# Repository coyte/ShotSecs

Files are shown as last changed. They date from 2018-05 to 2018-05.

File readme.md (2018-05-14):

# ShotSecs
Created a little timer that will keep track of how long power (240v) is applied. Originally developed to measure Espresso shots time, but probably useful for other applications.
The usual warnings about tinkering with 240V AC apply!!!

### Introduction
The original idea was that the logic and PSA would be housed inside the espressomachine, and the 7 segment display would be glued/mounted to the exterior of the machine. Hence they are two separate parts connected by a 10-strand data cable
### Hardware
The hardware consists of a little PCB (Kicad schematic & layout included) that hold a Atmega328p, two transistors and 10 resistors to control the 7-segment display.
On the input side I used some resistors and a optocoupler to detect power applied.
PSU, Atmega, optocoupler, resistors and transistors is mounted on the same PCB (220V and 5 V), intended to be drowned in a resin box when donw.

#### Connections (240Volts)
The timer needs a regular 240V connection to power up the Atmega and display. In addition it needs a connection of the applied power
Connect either P-N-Pd or N-P-Nd on the tree terminal block.
Where   P = phase or live wire from 240V mains
        N = null or neutral wire from 240V mains
        Pd= Phase from device to be measured
        Nd= null from device to be measured

### Software
The software is written in AVR C. It essentially is a timer that runs while power is detected by the optocoupler. The display will 'hold' the last known value if power is stopped. On re-applying the power the timer will restart at 0.

Have fun and be careful.

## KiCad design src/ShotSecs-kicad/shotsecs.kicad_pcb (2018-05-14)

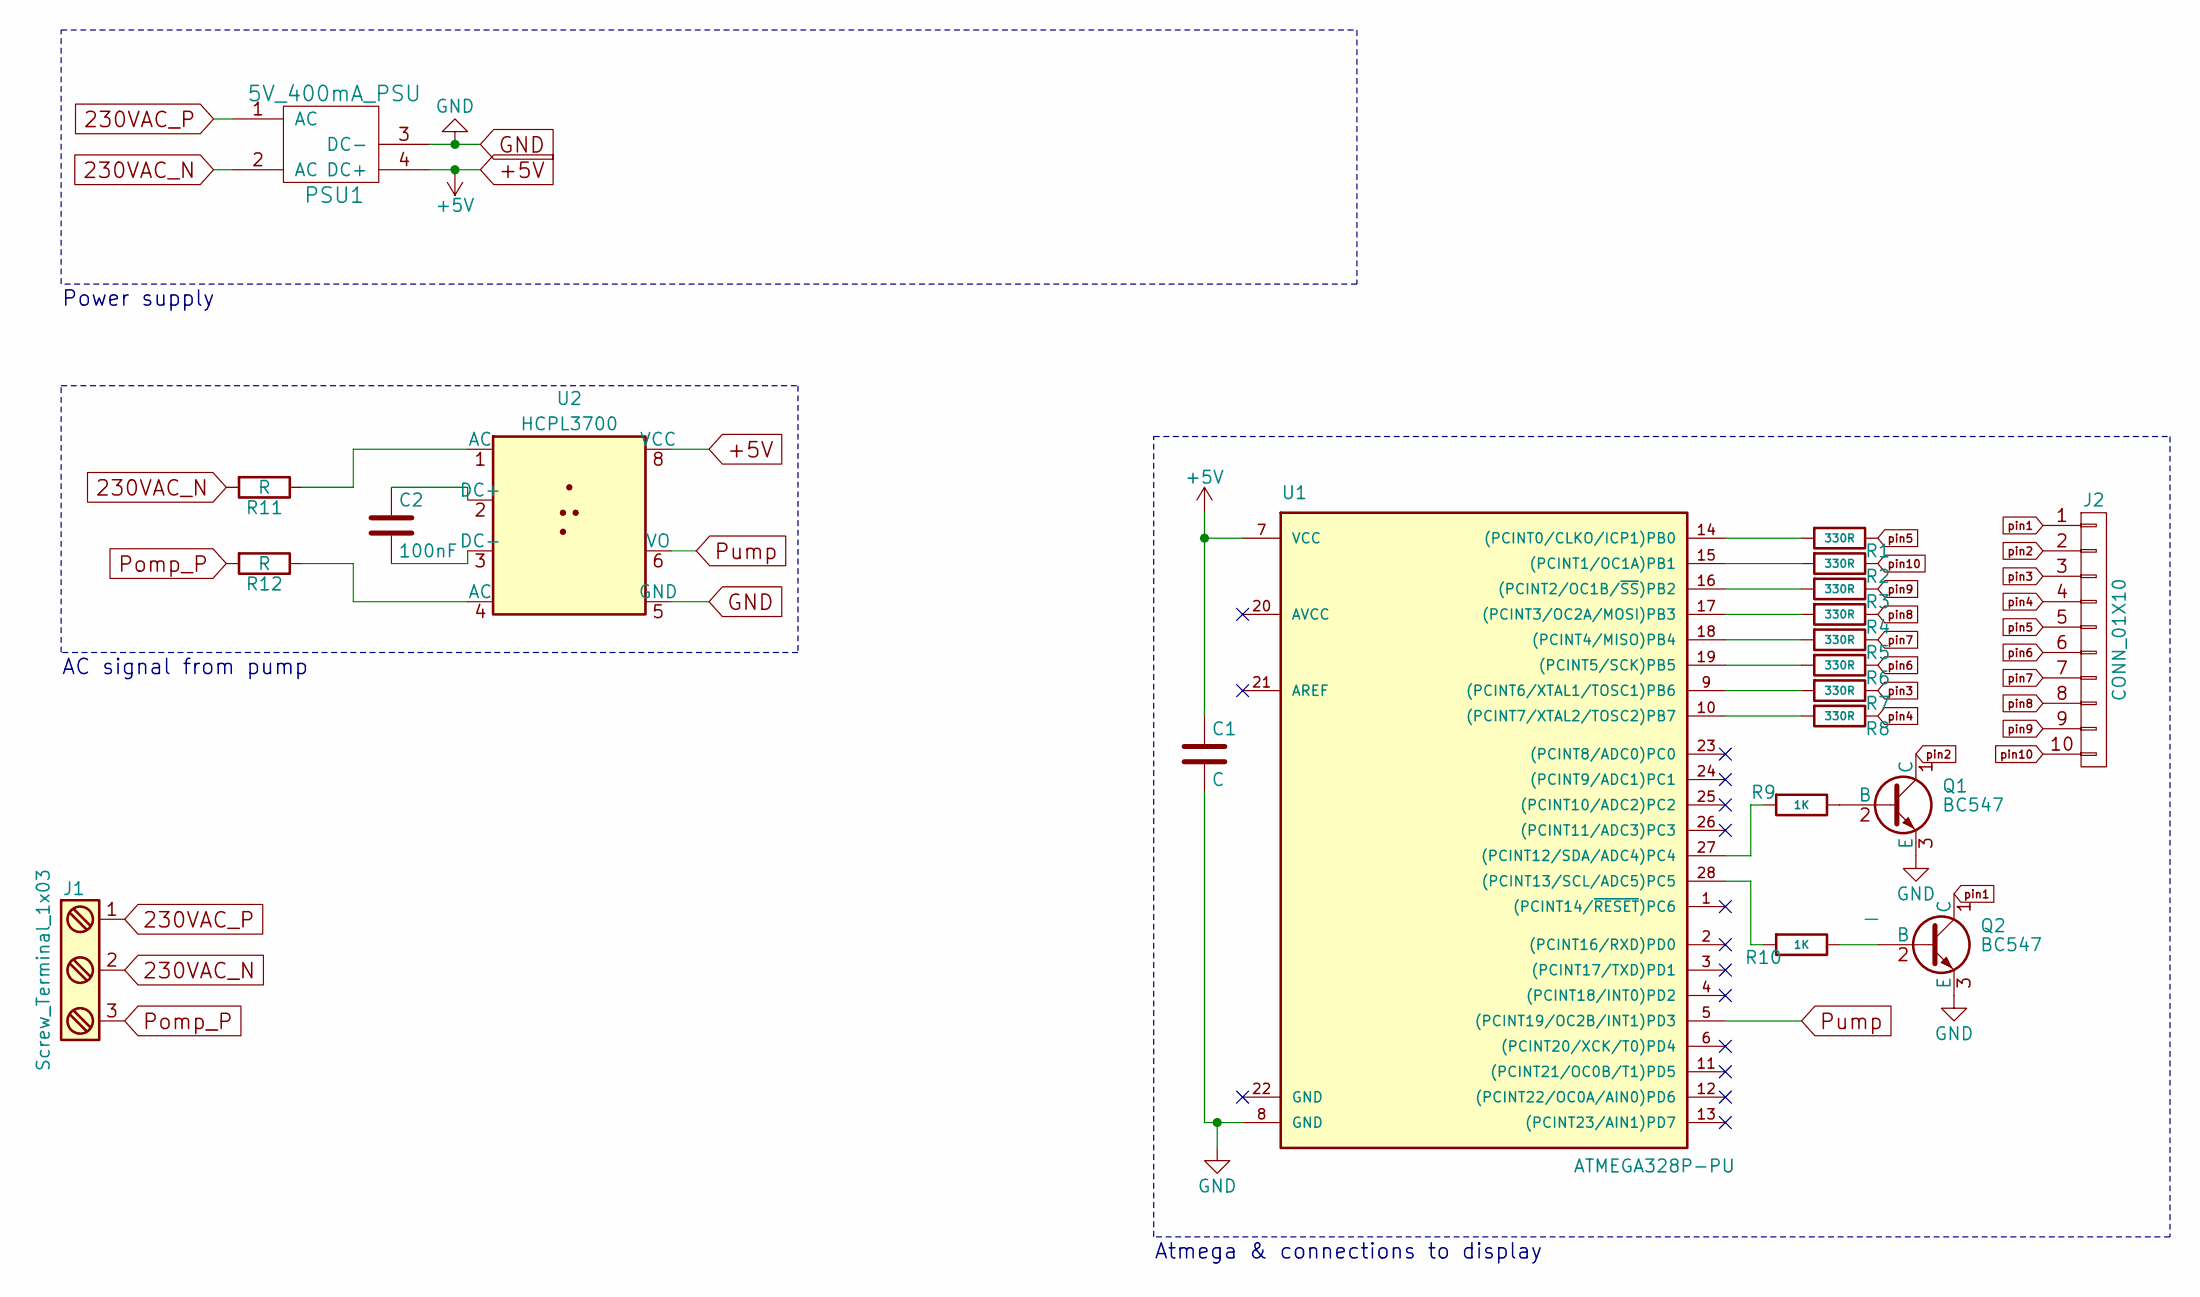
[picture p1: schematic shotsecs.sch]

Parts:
C1: C; C_Disc_D3.8mm_W2.6mm_P2.50mm
C2: 100nF; CP_Radial_D8.0mm_P5.00mm
J1: Screw_Terminal_1x03; TerminalBlock_Pheonix_PT-3.5mm_3pol
J2: CONN_01X10; Pin_Header_Straight_1x10_Pitch2.54mm
PSU1: 5V_400mA_PSU; HLK-PM01
Q1, Q2: BC547; TO-92_Molded_Narrow
R1, R2, R3, R4, R5, R6, R7, R8: 330R; R_Axial_DIN0207_L6.3mm_D2.5mm_P7.62mm_Horizontal
R9, R10: 1K; R_Axial_DIN0207_L6.3mm_D2.5mm_P7.62mm_Horizontal
R11, R12: R; R_Axial_DIN0207_L6.3mm_D2.5mm_P7.62mm_Horizontal
U1: ATMEGA328P-PU; DIP-28_W7.62mm
U2: HCPL3700; DIP-8_W7.62mm

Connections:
230VAC_N: J1.2, PSU1.2 (AC), R11.2
230VAC_P: J1.1, PSU1.1 (AC)
+5V: C1.1, PSU1.4 (DC+), U1.7 (VCC), U2.8 (VCC)
GND: C1.2, PSU1.3 (DC-), Q1.3 (E), Q2.3 (E), U1.8 (GND), U2.5 (GND)
unnamed: C2.1, U2.2 (DC+)
unnamed: C2.2, U2.3 (DC-)
unnamed: Q1.2 (B), R9.1
unnamed: Q2.2 (B), R10.1
unnamed: R1.2, U1.14 ((PCINT0/CLKO/ICP1)PB0)
unnamed: R2.2, U1.15 ((PCINT1/OC1A)PB1)
unnamed: R3.2, U1.16 ((PCINT2/OC1B/~SS~)PB2)
unnamed: R4.2, U1.17 ((PCINT3/OC2A/MOSI)PB3)
unnamed: R5.2, U1.18 ((PCINT4/MISO)PB4)
unnamed: R6.2, U1.19 ((PCINT5/SCK)PB5)
unnamed: R7.2, U1.9 ((PCINT6/XTAL1/TOSC1)PB6)
unnamed: R8.2, U1.10 ((PCINT7/XTAL2/TOSC2)PB7)
unnamed: R9.2, U1.27 ((PCINT12/SDA/ADC4)PC4)
unnamed: R10.2, U1.28 ((PCINT13/SCL/ADC5)PC5)
unnamed: R11.1, U2.1 (AC)
unnamed: R12.1, U2.4 (AC)
Pomp_P: J1.3, R12.2
Pump: U1.5 ((PCINT19/OC2B/INT1)PD3), U2.6 (VO)
pin1: J2.1, Q2.1 (C)
pin2: J2.2, Q1.1 (C)
pin3: J2.3, R7.1
pin4: J2.4, R8.1
pin5: J2.5, R1.1
pin6: J2.6, R6.1
pin7: J2.7, R5.1
pin8: J2.8, R4.1
pin9: J2.9, R3.1
pin10: J2.10, R2.1

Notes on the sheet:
Power supply
AC signal from pump
Atmega & connections to display

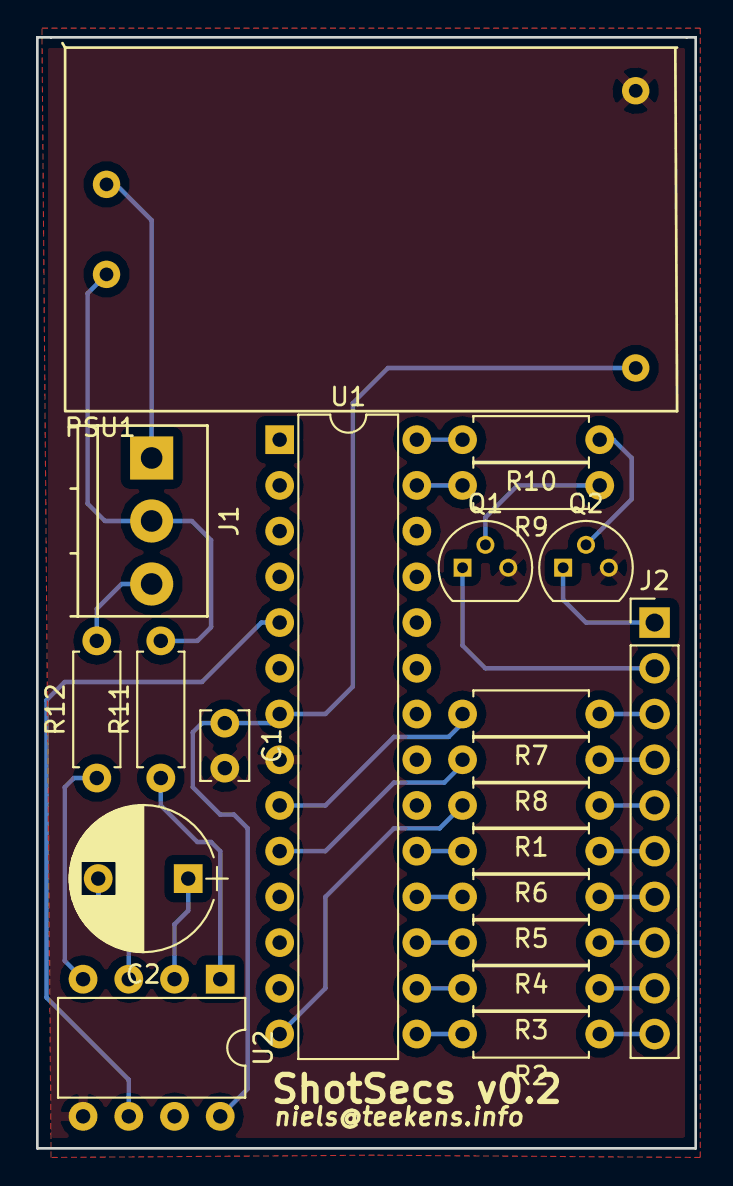
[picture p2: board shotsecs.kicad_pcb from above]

Board: 2 copper layers, 36.6 x 61.7 mm, 21 parts (0 on the bottom side), 32 nets.

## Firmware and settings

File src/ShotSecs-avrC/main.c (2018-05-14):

//Counter for espresso machine shot time.
//Fuses (L H E): E3 DA FD

#define F_CPU	4000000UL
#include <avr/io.h>
#include <util/delay.h>
#include "usart.h"


#define SegOne   0x20 //Activates digit 1
#define SegTwo   0x10 //activates digit 2

void main() {
    int debug=0; //set to 0 to disable debug msgs
	if (debug) USART_init(); // Initialize USART
	char seg_code[]={0x3f,0x6,0x5b,0x4f,0x66,0x6d,0x7c,0x7,0x7f,0x67}; //array of hex representations of decimal digits
    char seg_codeDP[]={0xbf,0x86,0xdb,0xcf,0xe6,0xed,0xfc,0x87,0xff,0xe7}; //array of hex representations of decimal digits, plus decimal point active
    int cnt,i;
	char String[4];
	cnt=0;
    
    
    /* Configure the ports as output */
    DDRB = 0xff; // Data lines
    DDRC = 0xff; // Control signal PORTC4-PORTC5
    DDRD = 0x00; // Input for motor
    PORTD = (1 << 3); //Enable pull-up


	void display(int counter) //Display the counter on the 7-segment display 
	{
		int time = 0;
		int seg1,seg2 = 0;
		if (counter<100) time = 10; else time=102; //time to keep tenths and wholes in display
		
		for (i = 0; i < time; i++) //loop to keep same digit displayed for a while
		{
			PORTC = SegOne; //segment one
			if (counter<100) 
			{
				seg1 = counter / 10;
				PORTB = seg_codeDP[seg1];
			}
			else
			{
				seg1 = (counter-100) / 10;
				PORTB = seg_code[seg1]; 
			}	
			_delay_ms(10);

			PORTC = SegTwo; //segment two
			if (counter<100) 
			{
				seg2 = counter % 10;
				PORTB = seg_code[seg2];
			}
			else
			{
				seg2 = (counter-100) % 10;
				PORTB = seg_code[seg2]; 
			}	
			_delay_ms(10);
		}
		if (debug) {
					USART_putstring(", Seg1: ");
					itoa(seg1, String, 10);
					USART_putstring(String);
					USART_putstring(", Seg2: ");
					itoa(seg2, String, 10);
					USART_putstring(String);
					USART_putstring("\n");
				}
	}
    
    
    
    
    while (1)
    {
		while(!(PIND & (1<<PD3)))
		{
    		for (cnt = 0; cnt <= 99; cnt++) // loop 0-999 tenth seconds
        	{
        		if (debug) {
					USART_putstring("cnt: ");
					itoa(cnt, String, 10);
					USART_putstring(String);
					USART_putstring("\n");    	// Pass the string to the USART_putstring function and sends it over the serial
				}
				if (PIND & (1<<PD3)) break;
        		display(cnt);
        		//if (PIND & (1<<PD3)) break;
        	}
			if (PIND & (1<<PD3)) break;
    		for (cnt = 110; cnt <= 199; cnt++) // loop 0-999 tenth seconds
        	{
        		if (debug) {
					USART_putstring("cnt: ");
					itoa(cnt, String, 10);
					USART_putstring(String);
					USART_putstring("\n");    	// Pass the string to the USART_putstring function and sends it over the serial
				}
				if (PIND & (1<<PD3)) break;
        		display(cnt);
        		if (PIND & (1<<PD3)) break;
        	}

		}    
		display(cnt);
}
}
